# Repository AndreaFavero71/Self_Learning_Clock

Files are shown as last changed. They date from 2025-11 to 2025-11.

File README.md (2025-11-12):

# Self-learning clock (SLC)

a DIY clock that learns its own internal drift to maintain high accuracy with minimal NTP synchronizations

It uses an ultra-low power development board, paired with a 4.2-inch, high-contrast e-paper display.
The clock is battery-operated, and one charge should last for months; I'll provide precise battery life data in due time.
<br><br>
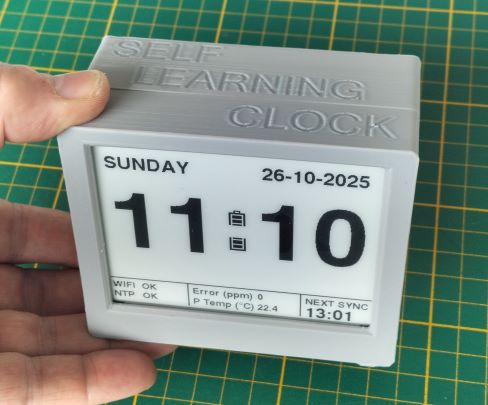
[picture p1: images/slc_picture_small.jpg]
title image
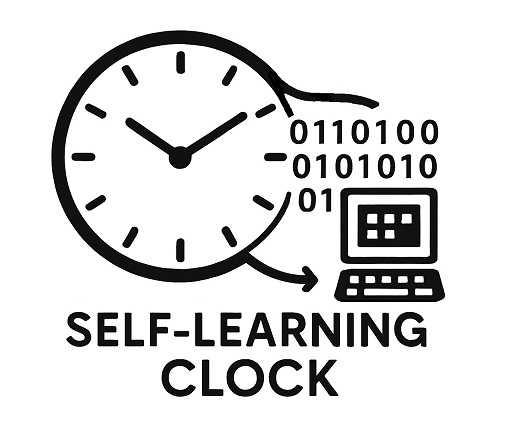
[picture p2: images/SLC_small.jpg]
title image


<br><br>
## Repo content
- all the Micropython files
- the Gerber files to make the Connections board

<br><br>
## For more information
More detailed informations at my [Instructables page](https://www.instructables.com/Self-Learning-Clock-SLC/)

<br><br>
## The Concept

Traditional NTP-based clocks frequently check in with time servers, which drains power and relies on a continuous network connection.
Their accuracy drifts until the next sync.

The Self-Learning Clock (SLC) takes a different approach: it observes its own timing errors and builds a software correction model for its internal oscillator's drift.

By applying this adaptive correction, it achieves excellent short-term accuracy and minimal long-term drift (the last gets fully compensated at NTP syncs).

After an initial learning period, the clock maintains an accuracy of approximately ±2 seconds over a 12-hour period, with just two NTP syncs per day.

The initial learning takes about two days, but the learning process never stops, allowing the SLC to continuously refine its corrections.

A high-level flowchart is attached, which better explains how the system works.

After researching online, I could not find any prior project with this specific approach. While there are many accurate timekeeping solutions available, I wanted to see how far I could push the accuracy of a microcontroller's own hardware, in a battery-operated device, and I'm quite pleased with the results.

<br><br>
## Why This Matters:
Microcontrollers like the ESP32 contain two types of oscillators:
- High-power mode: Uses a stable and precise crystal oscillator.
- Low-power mode (light sleep): Uses energy-efficient but imprecise RC oscillators that can accumulate minutes of error per day.

While external RTC modules with backup batteries can solve this problem, the SLC achieves similar precision using only the microcontroller itself.
This enables true, long-lasting battery operation without any additional hardware.

<br><br>
## Why "Self-Learning"?
In this context, "learning" refers to a deterministic self-calibration process.

The clock models and compensates for its own hardware characteristics. It's not artificial intelligence, but a straightforward mathematical analysis.

The system compares the internal clock deviation (in PPM) against a trusted source (NTP servers) and applies a filtered correction to the displayed time.

<br><br>
## Key features

#### Adaptive Drift Compensation:
- Learns and corrects the microcontroller's oscillator drift through periodic NTP synchronization, creating an increasingly accurate internal timing model.
- There is no need to manually calibrate the resonator; the code handles compensation automatically.
- Ultra-Low Power Consumption (<0.75 mAh average):
- Implements finely tuned light-sleep cycles with ultra-short wakeups (≈0.8 seconds active per minute).

#### Smart Time Management:
- Automatically handles time zones and Daylight Saving Time (DST) with configurable rules for different regions (e.g., EU, US, Australia).

#### High-Contrast 4.2" E-Paper Display:
- Features gigantic 110-point digits for excellent readability.
- It uses partial refreshes for efficiency and a full refresh every 60 updates to prevent ghosting.
- The display updates immediately after the minute changes (when seconds are between 0 and 5).
- #### The display also shows useful status information:
  - Battery level (displayed in place of the colon between hours and minutes)
  - Residual timing error (in PPM)
  - Microprocessor temperature (°C/°F)
  - Time of the next NTP sync
  - Status of the last WiFi connection
  - Status of the last NTP synchronization

#### WiFi Connectivity:
- The clock requires a WiFi network for NTP synchronization. While this is a limiting factor, WiFi is common in most modern homes.

#### Additional Notes:
The learning and correction process continuously adapts to variations that might arise from temperature changes or component aging.

The very small duty cycle (<1.5%) drastically limits the microprocessor's self-heating, allowing it to be 'sealed' in an enclosure.
This isolation protects the processor from sudden room temperature fluctuations, leading to a more stable drift characteristic.

Long-term accuracy validation is an ongoing process: The more precise the clock becomes, the longer the test period required to characterize its performance fully.

So far, the longest continuous test run has been one week, and I will provide more detailed long-term data as it becomes available.

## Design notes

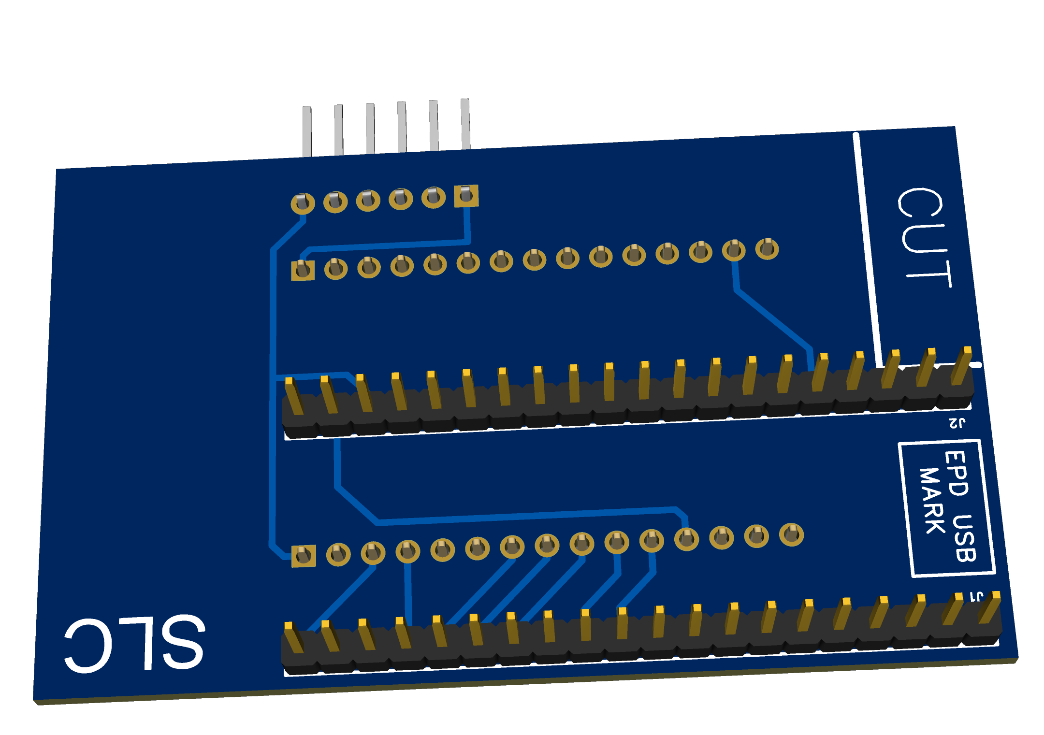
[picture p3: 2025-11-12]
board/3D_PCB1_2025-10-22 (7).png

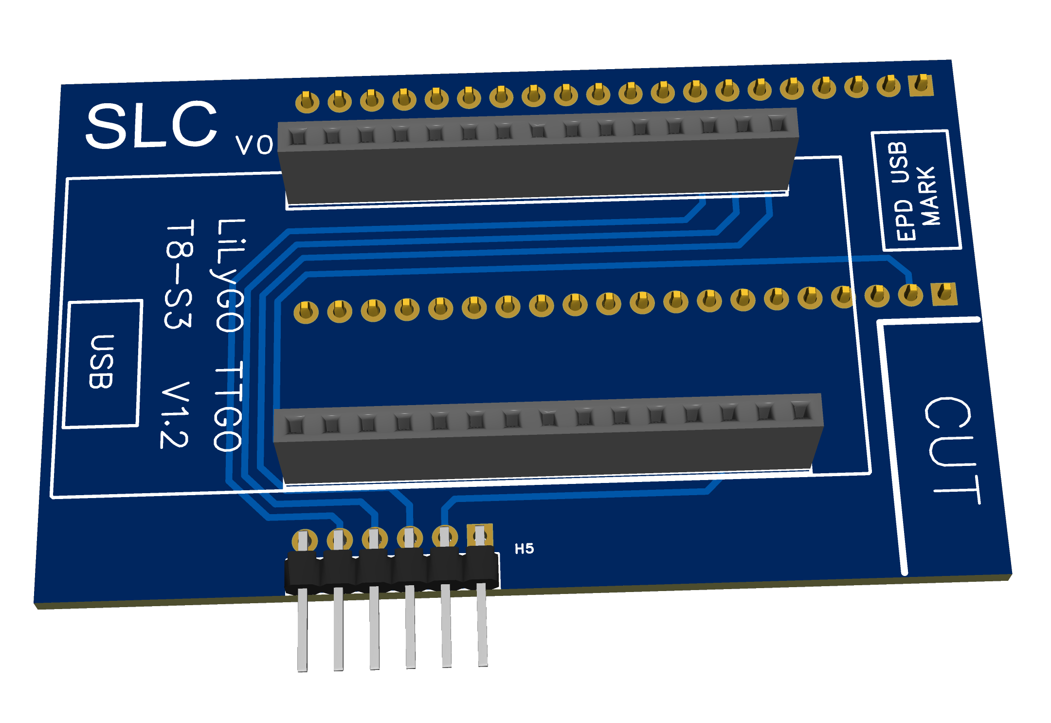
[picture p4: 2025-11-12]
board/3D_PCB1_2025-10-22.png

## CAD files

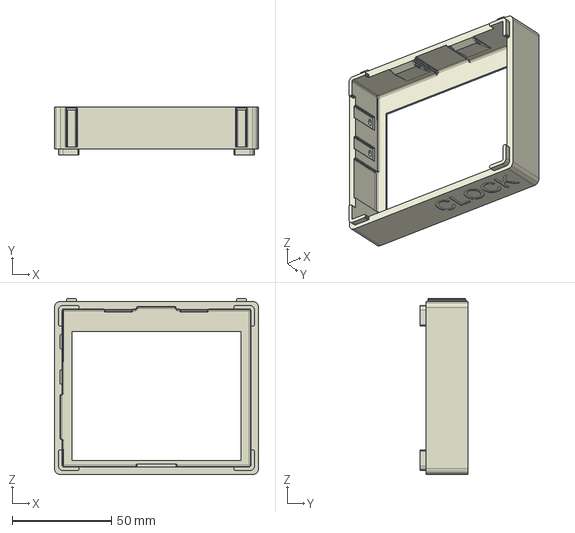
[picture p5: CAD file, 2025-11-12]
3d_model/step/front_v4.stp
102.6 x 24.1 x 88.6 mm

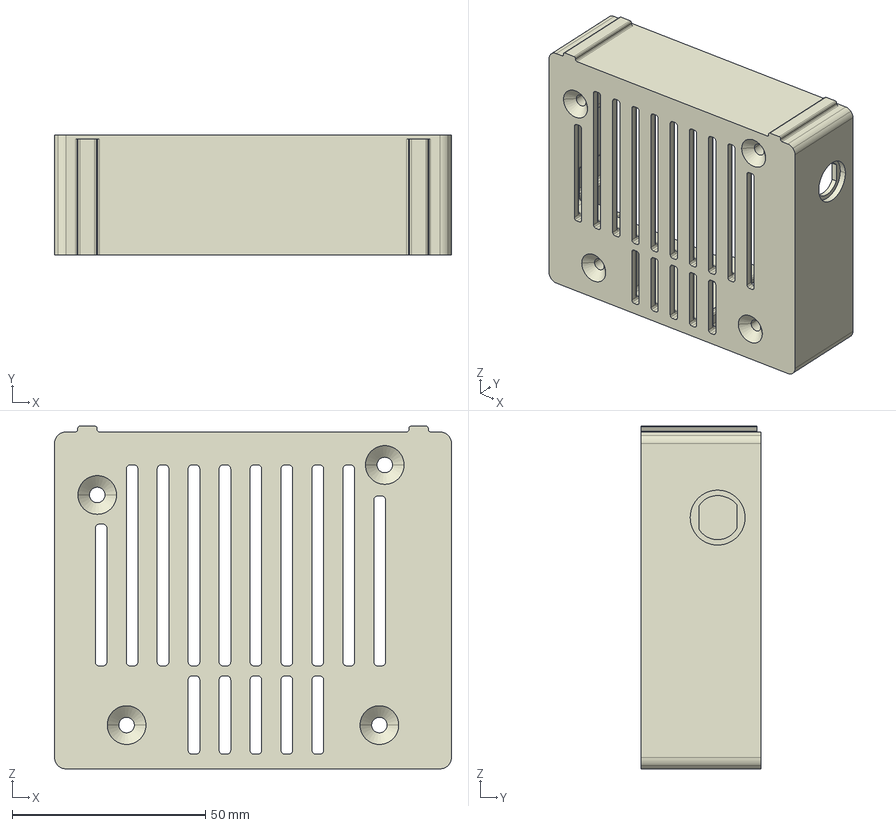
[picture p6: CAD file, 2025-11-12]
3d_model/step/back_v5_LP785060.stp
102.6 x 30.9 x 88.6 mm

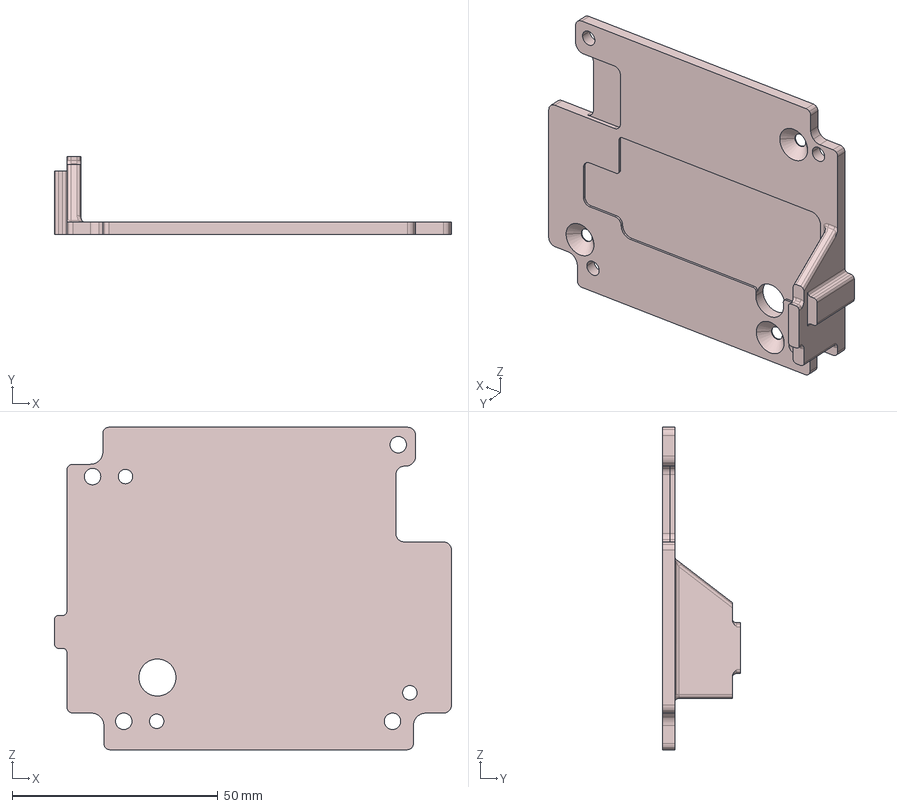
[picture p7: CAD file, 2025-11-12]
3d_model/step/panel_v4_LP773575.stp
96.5 x 19.0 x 78.4 mm

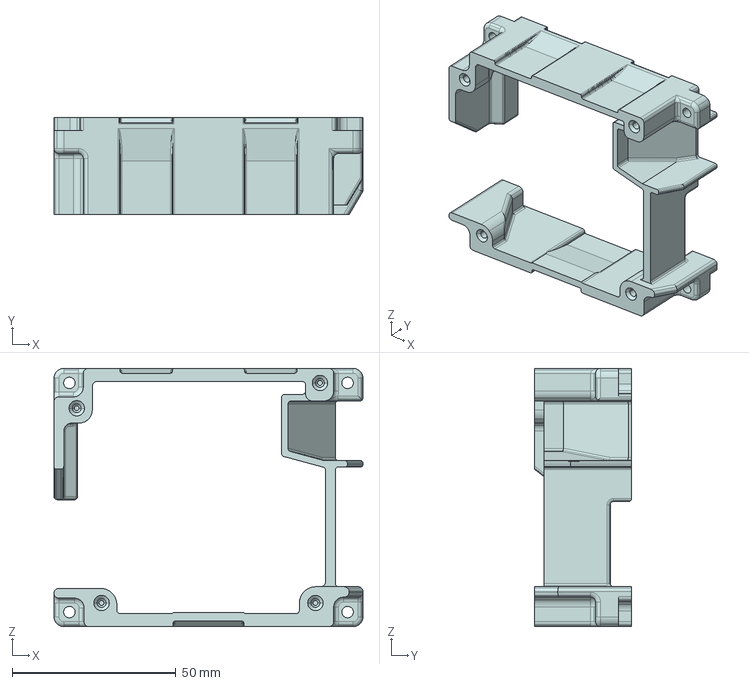
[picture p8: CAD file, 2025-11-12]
3d_model/step/frame_v4.stp
94.4 x 29.7 x 78.9 mm

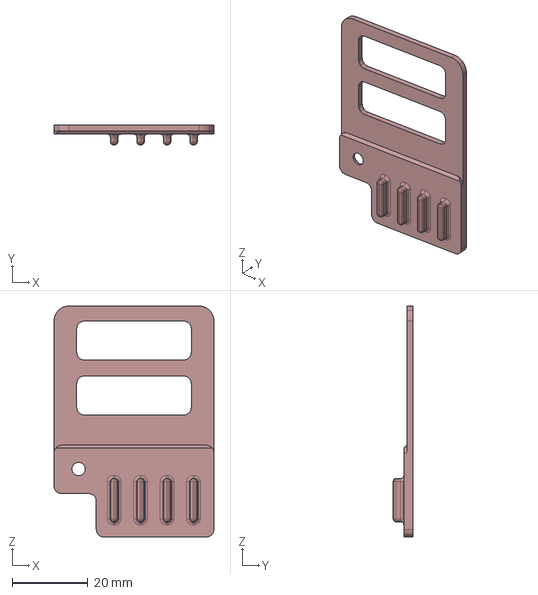
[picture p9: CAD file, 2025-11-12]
3d_model/step/clip_v5.stp
42.3 x 5.20 x 61.0 mm

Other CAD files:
3d_model/step/panel_v5_LP785060.stp

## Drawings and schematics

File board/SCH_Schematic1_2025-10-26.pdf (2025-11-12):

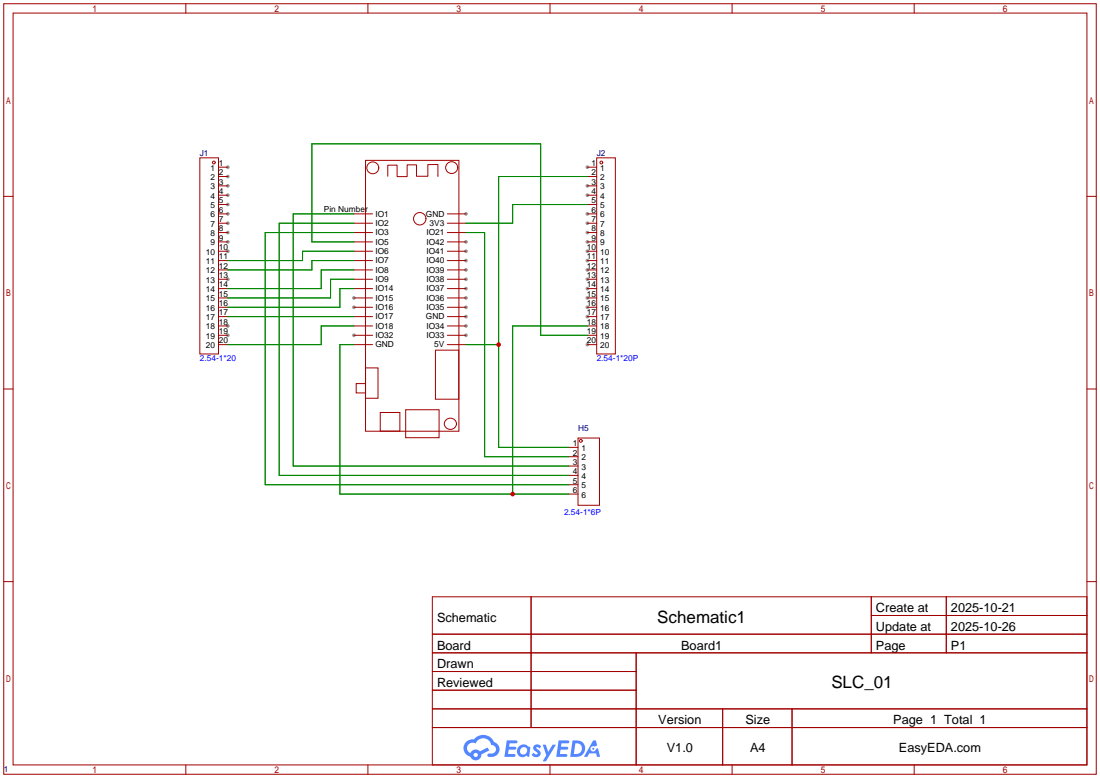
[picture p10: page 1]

Schematic | Schematic1 | Create at | 2025-10-21

Update at | 2025-10-26

Board | Board1 | Page | P1
Drawn | | SLC_01
Reviewed

Version | Size | Page 1 Total 1
V1.0 | A4 | EasyEDA.com

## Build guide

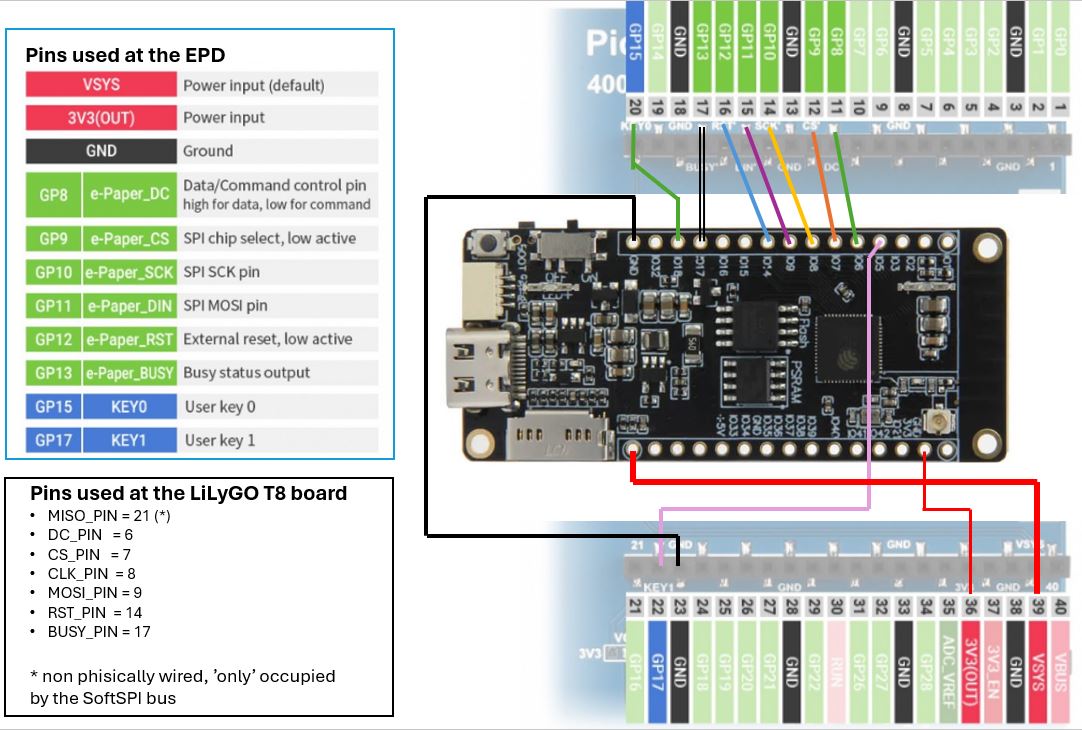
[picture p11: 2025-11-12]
board/Wiring.JPG

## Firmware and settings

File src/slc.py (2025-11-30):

"""
Andrea Favero 20251130


Self-Learning Clock (MicroPython)

More info at:
  https://github.com/AndreaFavero71/Self_Learning_Clock
  https://www.instructables.com/Self-Learning-Clock-SLC/


NTP is used to periodically discipline the clock.
The MCU’s internal clock interval (ticks counting) is compared with the one obtained via NTP,
allowing the system to learn its own drift and self-correct between synchronizations.
The internal timing mechanism itself is not altered by these corrections; instead, the
displayed time is adjusted to minimize deviation. This approach reduces time drift while
lowering the NTP synchronization frequency, thereby minimizing energy consumption.

The display refresh cadence is adapted so that the new time is updated when the
interpreted seconds fall between 0 and 5 of each minute.
Light-sleep duration is maximized to reduce power consumption in battery-operated clocks.
The code has been developed on a LilyGO T8 development board (ESP32-S3 based, with 8 MB PSRAM)

The used display is a Waveshare 4.2-inch (400×300) 4-grayscale e-paper Pico version:
https://www.waveshare.com/wiki/Pico-ePaper-4.2

(Optional) If predefined SSID/passwords are not available, or fail to connect, the code automatically
searches for open networks, check settings at config.py.




MIT License

Copyright (c) 2025 Andrea Favero

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

__version__ = "0.2.1"


# import standard modules
from utime import ticks_ms, gmtime, time, sleep_ms, ticks_diff
from esp32 import NVS, mcu_temperature
from machine import lightsleep
from collections import deque
import uasyncio as asyncio
import sys, gc

# import SLC custom modules
from network_manager import NetworkManager
from time_manager import TimeManager
from display_manager import Display
from battery_manager import Battery
from wdt_manager import WDTManager
from lib.config import config



class SelfLearningClock:
    def __init__(self, logo_time_ms):
        
        if config.DEBUG:
            print()
            print("#" * 41)
            print("#  Clock started. Press Ctrl+C to stop  #")
            print("#" * 41)
            print()
        
        
        # reducing ESP32-S3 frequency to lower power consumption
        # 80MHz is the minimum allowed frequency to maintain wlan function
        freq = 80_000_000
        
        # check presence or make a folder for the log related files
        self._make_folder("log")
        
        # initialize the module for time management
        self.time_mgr = TimeManager(config)
        
        # initialize WDT manager, before the modules where it is passed
        if config.WDT_ENABLED:
            self.wdt_manager = WDTManager()
        else:
            self.wdt_manager = False
        
        # initialize display module, by also passing the WDT manager
        self.display = Display(wdt_manager = self.wdt_manager,
                               lightsleep_active = config.LIGHTSLEEP_USAGE,
                               battery = config.BATTERY,
                               degrees = config.TEMP_DEGREES,
                               hour12 = config.HOUR_12_FORMAT,
                               am_pm_label = config.AM_PM_LABEL,
                               debug = config.DEBUG,
                               logo_time_ms = logo_time_ms
                               )
        
        # initialize the network manager module, by also passing the WDT manager
        self.network_mgr = NetworkManager(self.wdt_manager)

        # case of error on initializing the network manager
        if not self.network_mgr.secrets:
            # error info is showed to the display and code is stopped
            self.display.text_on_logo("ERROR: SECRETS.JSON", x=-1, y=-1, show_time_ms=2000)
            
            if config.DEBUG:
                print("[ERROR]    Issues with the secret.json file in /lib folder")
                print("[INFO]     If you aim using open networks, set OPEN_NETWORKS as True in config.py")
            
            # code is stopped
            sys.exit(1)
        
        # case of battery, initialize the battery manager module
        if config.BATTERY:
            self.battery = Battery(debug=config.DEBUG)
        else:                       # case of no battery
            self.batt_voltage = -1  # assign an arbitrary value to the variable 
            self.batt_level = -1    # assign an arbitrary value to the variable
        
        # initialize WDT (after all components are initialized)
        if config.WDT_ENABLED:
            self.wdt_manager.initialize() 
        
        # initialize global variables
        self.smoothed_drift_ppm = 0
        self.last_smoothed_drift_ppm = 0
        self.current_sync_interval_ms = config.NTP_SYNC_INTERVAL_MS
        self.display_interval_ms = max(60000, config.DISPLAY_REFRESH_MS)     # EPD refresh time must be at least 60 secs (nominal)
        self.max_display_interval_ms = int(1.1 * self.display_interval_ms)   # adapted min EPD refresh time is 0.9 x
        self.min_display_interval_ms = int(0.9 * self.display_interval_ms)   # adapted max EPD refresh time is 1.1 x

        # timekeeping variables
        self.last_ntp_sync_ticks_ms = 0
        self.last_ntp_epoch_ms = 0
        self.last_ntp_epoch_s = 0
        self.ntp_total_delay_ms = 0
        self.ntp_offset_ms = 0
        self.time_tuple = (0,0,0,0,0,0)
        self.last_sync_day = -1
        self.next_sync = '99:99'
        
        # state variables
        self.first_cycle = True
        self.epd_full_update = False
        self.upload_files = False
        self.cycle_counter = 0
        self.sync_count = 0
        self.display_update_count = 0 
        
        # temperature smoothing
        self.mcu_temp = deque([], 16)
        
        # lists for trend analysis
        if config.DEBUG or config.PUSH_FILE_ENABLED:
            datapoints = 50
            self.mcu_temp_list = deque([], datapoints)
            self.error_ms_list = deque([], datapoints)
            self.correction_ms_list = deque([], datapoints)
            self.measured_drift_ppm_list = deque([], datapoints)
            self.smoothed_drift_ppm_list = deque([], datapoints)
            self.ntp_offset_ms_list = deque([], datapoints)
            self.ntp_tot_delay_ms_list = deque([], datapoints)
            self.ntp_rnd_latency_ms_list = deque([], datapoints)
            self.display_interval_ms_list = deque([], datapoints)
        
        ##############################################################
        ##############################################################
        # force wdt operation for debug purpose (do not uncomment it)
        # for i in range(3):
        #    self.network_mgr.feed_wdt(label="test wdt")
        #    sleep_ms(int(1.3 * config.DISPLAY_REFRESH_MS))
        ##############################################################
        ##############################################################
        
        
    
    def get_reset_reason(self):
        """Checks the reason for the MCU boot"""
        from machine import reset_cause, PWRON_RESET, HARD_RESET, WDT_RESET, DEEPSLEEP_RESET, SOFT_RESET
        
        reset_reason, reset_message = None, None
        reset_reason = reset_cause()
        reset_message = {
            PWRON_RESET: "POWER-ON RESET",
            HARD_RESET: "HARD RESET",
            WDT_RESET: "WATCHDOG RESET",
            DEEPSLEEP_RESET: "DEEPSLEEP WAKE",
            SOFT_RESET: "SOFT RESET"
        }.get(reset_reason, f"???: {reset_reason}")
        
        del reset_cause, PWRON_RESET, HARD_RESET, WDT_RESET, DEEPSLEEP_RESET, SOFT_RESET
        return reset_reason, reset_message
    
    
    
    
    def write_reset_reason(self, reset_reason, reset_msg):
        """Writes the reset reason to a text file, trimming old entries if needed."""

        MAX_RECORDS = 100

        # feed watchdog
        self.network_mgr.feed_wdt(label="write_reset_reason")

        try:
            # try reading existing lines (if file exists)
            try:
                with open(config.RESET_FILE_NAME, "r") as f:
                    lines = f.readlines()
            except OSError:
                lines = []

            # build the new log line
            timestamp = gmtime(time())  # (year, month, mday, hour, minute, second, ...)
            formatted_time = f"{timestamp[0]:04d}-{timestamp[1]:02d}-{timestamp[2]:02d} {timestamp[3]:02d}:{timestamp[4]:02d}:{timestamp[5]:02d}"
            new_line = f"Time: {formatted_time},  RST_reason: {reset_reason},  RST_msg: {reset_msg}\n"

            # append and trim if necessary
            lines.append(new_line)
            if len(lines) > MAX_RECORDS:
                lines = lines[-MAX_RECORDS:]

            # rewrite the file
            with open(config.RESET_FILE_NAME, "w") as f:
                for line in lines:
                    f.write(str(line))

        except Exception as e:
            if config.DEBUG:
                print(f"[ERROR]    Failed to write reset reason: {e}")
    
    
    
    
    def get_discipline(self, key=1):
        """Read discipline factor from NVS"""
        
        if config.QUICK_CHECK and config.DEBUG:
            print("\n[DEBUG]    Existing 'discipline factor' is not loaded when config.QUICK_CHECK")
            return None
        
        try:
            nvs = NVS("storage")
            buffer = bytearray(16)
            nvs.get_blob(str(key), buffer)
            value = buffer.decode().strip('\x00') 
            if config.DEBUG:
                print(f"[DEBUG]    A discipline factor was available: {value}")
            return self._convert_to_number(value)
        
        except Exception as e:
            if config.DEBUG:
                if e.errno == -0x1102:
                    print("[DEBUG]    Variable 'discipline factor' not found (not saved in esp32.NSV yet)")
                else:
                    print(f"[ERROR]    Issue on reading from esp32.NSV: {e}")
            return None
    
    
    
    def save_discipline(self, discipline_factor, key=1):
        """Save discipline factor to NVS"""
        
        if config.QUICK_CHECK and config.DEBUG:
            print("[DEBUG]    Variable 'discipline factor' is not saved when config.QUICK_CHECK")
            return None
        
        try:
            nvs = NVS("storage")
            nvs.set_blob(str(key), str(discipline_factor).encode())
            nvs.commit()
        except Exception as e:
            if config.DEBUG:
                print(f"[ERROR]   Issue on saving to esp32.NSV: {e}")
            raise
    
    
    
    def write_to_csv(self, epoch, temp, error_ms, ntp_offset_ms, rnd_latency_ms, tot_latency_ms):
        """
        Writes the stats on a tab separated file, trimming the file if too large.
        File trimming is made in RAM, and it considers a small file size.
        """

        MAX_RECORDS = 200  # keep only the newest 200 records (excluding header)

        if config.DEBUG:
            print(f"[DEBUG]    write_to_csv called with epoch={epoch}, file={self.stats_file_name}")

        self.network_mgr.feed_wdt(label="write_to_csv")

        try:
            # create file with header if not yet done
            if not hasattr(self, "csv_header_written"):
                with open(self.stats_file_name, "w") as file:
                    header = ("epoch\ttemp\terror_ms\tcorrection_ms\tdrift_ppm\t"
                              "ntp_offset_ms\trnd_latency_ms\ttot_latency_ms\t"
                              "smoothed_ppm\tdisplay_interval_ms\tbatt_voltage\t"
                              "battery_level\n")
                    file.write(header)
                self.csv_header_written = True

            # read existing lines
            try:
                with open(self.stats_file_name, "r") as file:
                    lines = file.readlines()
            except OSError:
                # file may not exist yet
                lines = ["epoch\ttemp\terror_ms\tcorrection_ms\tdrift_ppm\t"
                         "ntp_offset_ms\trnd_latency_ms\ttot_latency_ms\t"
                         "smoothed_ppm\tdisplay_interval_ms\tbatt_voltage\t"
                         "battery_level\n"]

            # build new data line
            new_line = (
                f"{epoch}\t{temp:.2f}\t{error_ms}\t{self.correction_ms}\t"
                f"{self.measured_drift_ppm:.6f}\t{ntp_offset_ms}\t{rnd_latency_ms}\t"
                f"{tot_latency_ms}\t{self.smoothed_drift_ppm:.6f}\t{self.display_interval_ms}\t"
                f"{self.batt_voltage}\t{round(self.batt_level,3)}\n"
            )

            # append and trim if necessary
            lines.append(new_line)

            # first line is header → data start from index 1
            if len(lines) - 1 > MAX_RECORDS:
                # keep header + last MAX_RECORDS lines
                lines = [lines[0]] + lines[-MAX_RECORDS:]

            # write back
            with open(self.stats_file_name, "w") as file:
                for line in lines:
                    file.write(line)

        except Exception as e:
            print(f"[ERROR]    write_to_csv failed: {e}")
            raise
    

    
    
    def get_temperature(self):
        """Get temperature from MCU"""

        # wdt feeding
        self.network_mgr.feed_wdt(label="get_temperature")
        
        # temp threshold (celsius) to plot a warning on the display
        t_warning_c = 50
        
        # gets the MCU temperature
        temperature_c = mcu_temperature()
        
        # case Celsius is set at the config.py
        if config.TEMP_DEGREES == "C":
            temperature = temperature_c
            if temperature_c > t_warning_c:
                self.display.text_on_logo(f"PROCESSOR TEMP {round(temperature_c,0)} C", x=-1, y=-1, show_time_ms=20000)
        
        # case Fahrenheit is set at the config.py
        elif config.TEMP_DEGREES == "F":
            temperature = self._c_to_f(temperature_c)
            if temperature_c > t_warning_c:
                self.display.text_on_logo(f"PROCESSOR TEMP {round(temperature,0)} F", x=-1, y=-1, show_time_ms=20000)
        else:
            if config.DEBUG:
                print("[ERROR]   TEMP_DEGREES at config must be 'C' or 'F' ")
            self.display.text_on_logo("ERROR: C or F DEG.", x=-1, y=-1, show_time_ms=20000)
            
            # forced garbage collection
            gc.collect()
        
        # averaging the temperatures previouly gathered
        if len(self.mcu_temp) > 0:
            avg_temp = sum(self.mcu_temp)/len(self.mcu_temp)
        else:
            avg_temp = temperature
        
        # append the last temp measured
        self.mcu_temp.append(temperature)
        
        # low-pass filter
        temp = 0.8 * avg_temp + 0.2 * temperature

        return round(temp, 2)
    
    
    
    
    def update_display(self, current_temp, plot_all=False):
        """
        Update the display
        When plot_all is False then only the changed fields gets updated on the display.
        When plot_all is True, all the fields and graphics gets updated on the display.
        Tipically, the plot_all=False is managed as partial_update technology of the EPD,
        unless it is time for a full refress (preventing ghosting).
        """
        
        # wdt feeding
        self.network_mgr.feed_wdt(label="update_display_1")
        
        try:    
            
            # retrieve the single gigits for hour and minute
            H1, H2, M1, M2, am = self.time_mgr.get_time_digits(self.time_tuple)
            
            # retrieve the date fields
            dd, day, d_string = self.time_mgr.get_date(self.time_tuple)
            
            # forced garbage collection
            gc.collect()
            
            # set the battery_low flag as False
            battery_low = False
            
            # if battery presence and its voltage below threshold
            if config.BATTERY and self.batt_voltage < config.BATTERY_WARNING:
                # set the battery_low flag as True
                battery_low = True
            
            # send the updated info to the display Class
            self.display.show_data(H1, H2, M1, M2, dd, day, d_string, current_temp, self.batt_level,
                                   self.res_error_ppm, self.next_sync, self.network_mgr.wifi_bool,
                                   self.network_mgr.ntp_bool, am, battery_low=battery_low, plot_all=plot_all)

            # wdt feeding
            self.network_mgr.feed_wdt(label="update_display_2")
        
        except Exception as e:
            if config.DEBUG:
                print(f"[ERROR]    Display error: {e}")
            raise
    
    
    
    
    def goto_sleep(self, total_sleep_ms):
        """Function handling the needed steps to enter lightsleep"""
        
        # wdt feeding
        self.network_mgr.feed_wdt(label="goto_sleep_1")
                    
        # sleeping time must be positive
        total_sleep_ms = max(0, total_sleep_ms)
        
        # case the lightsleep is set False
        if not config.LIGHTSLEEP_USAGE:
            if config.DEBUG:
                print(f"[DEBUG]    Going to sleep for {total_sleep_ms} ms")
            
            # normal sleeping function is used instead of the lighsleep one
            sleep_ms(total_sleep_ms)
        
        # case the lightsleep is set True
        elif config.LIGHTSLEEP_USAGE:
            
            # case the radio is still active
            if self.network_mgr.wlan.active() or self.network_mgr.wlan.isconnected():
                
                # disable the radio, and track the needed ime
                wlan_disabling_t_ms = self.network_mgr.disable_wifi()
                
                if total_sleep_ms > wlan_disabling_t_ms:
                    total_sleep_ms -= wlan_disabling_t_ms
                else:
                    total_sleep_ms = 0
            
            # wdt feeding
            self.network_mgr.feed_wdt(label="goto_sleep_2")
            
            if config.DEBUG:
                t_enter_lightsleep_ms = ticks_ms()
                print(f"[DEBUG]    Entering lightsleep for {total_sleep_ms} ms")
            
            # entering the lightsleep period
            lightsleep(total_sleep_ms)
            
            if config.DEBUG:
                print("[DEBUG]    Quitting lightsleep")
        
        # wdt feeding
        self.network_mgr.feed_wdt(label="goto_sleep_3")
        
    
    
    
    
    async def run(self):
        """Main clock execution"""

        # NTP sync configuration based on clock time (not on elapsed period)
        # if Country uses DST, it is better to atrget 3:15, to get the time updated right after the official switch hour
        # if Country does not use DST, choose the time you prefer NTP sync (by night should be faster, draining less battery)
        # This control is only active after the initial learning (sync_interval_ms >= 8 hours)
        sync_target_hour = 3       # 3 (not 03) for 3 AM
        sync_target_minute = 15    # 15 (not :15) for 03:15 AM
        self.last_sync_day = -1    # last day NTP synced at target hour (-1 forces first time)
        
        # load discipline factor
        discipline_factor = self.get_discipline()
        
        # check the discipline_factor
        if discipline_factor is None:
            self.smoothed_drift_ppm = 0
            if config.DEBUG:
                print("[DEBUG]    Not available a prior discipline_factor, it will be saved in a few days from now")
        else:
            self.smoothed_drift_ppm = discipline_factor
            if config.DEBUG:
                print(f"[DEBUG]    Loaded the latest discipline_factor: {discipline_factor}")
        
        # assign smoothed_drift_ppm to last_smoothed_drift_ppm
        self.last_smoothed_drift_ppm = self.smoothed_drift_ppm
        
        # retieve the reset reason
        reset_reason, reset_msg = self.get_reset_reason()
        if config.DEBUG:
            print(f"\n[INFO]     Last reset reason: {reset_msg}\n")
        
        # save the reset reason to a text file
        self.write_reset_reason(reset_reason, reset_msg)

        # plot the SLC logo with the SLC code version
        self.display.text_on_logo(f"SLC  VERSION:  {__version__}", x=-1, y=-1, show_time_ms=5000)
        
        # plot the SLC logo with a custom text underneath
        self.display.text_on_logo("WIFI  CONNECTION  ...", x=-1, y=-1, show_time_ms=2000)
        
        # forced garbage collection
        gc.collect()
        
        # wdt feeding
        self.network_mgr.feed_wdt(label="before making 1st wlan")
        
        # initialize WiFi
        self.network_mgr.connect_to_wifi(blocking=True)
        
        # check if error due to wifi connection
        if not self.network_mgr.wifi_bool:
            self.display.text_on_logo("ERROR: WIFI NETWORKS", x=-1, y=-1, show_time_ms=2000)
            sys.exit(1)
        
        # check if the wifi has internet connection
        ret = await self.network_mgr.is_internet_available(blocking=True)
        
        # check if error due to internet access
        if not ret:
            self.display.text_on_logo("ERROR: NO INTERNET", x=-1, y=-1, show_time_ms=2000)
            sys.exit(1)
        
        # wdt feeding   
        self.network_mgr.feed_wdt(label="after making 1st wlan")
        
        # check the IP addresses of the NTP server(s)
        ntp_servers_ip = await self.network_mgr.get_ntp_servers_ip(repeats=5)
        
        # check if error ar resolving the NTP servers addresses (blocking)
        if len(ntp_servers_ip) == 0:
            self.display.text_on_logo("ERROR: NTP DNS", x=-1, y=-1, show_time_ms=0)
            sys.exit(1)
        
        # preparig for the real first NTP sync
        if config.DEBUG:
            print("\n[INFO]     Performing first NTP sync ...")
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

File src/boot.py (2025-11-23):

# This file is executed on every boot (including wake-boot from deepsleep)


##################################################################
# To get the code starting at the boot, uncomment the below code #
# Before doing so, ensures the code is running without errors    #
##################################################################



# from utime import sleep_ms
# t_ms = 20000
# print(f"\n\n{t_ms//2000} seconds sleep time to delay the WDT")
# print("This time should suffice to interrupt the code via CTRL + C (preventing automatic script execution)\n")
# sleep_ms(t_ms//2)
# 
# import asyncio
# import slc
# asyncio.run(slc.main(logo_time_ms=int(t_ms//2)))

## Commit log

2025-11-12 initial commit
    initial commit
    initial commit
    Added step files
    rev_01
    rev_01
    [back_v5_LP785060.stp, clip_v5.stp, frame_v4.stp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]
2025-11-23 rev 0.2.0
    Improved battery manager with clearer function separation and enhanced debug output. Refactored network manager for better handling of open networks, WiFi connection logic, and transmission power opt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
2025-11-30 Add 12-hour time format
    Introduces configuration options for 12-hour time format and AM/PM label in config.py. Updates display_manager, time_manager, and slc.py to support and render 12-hour time format and AM/PM indicators. Refactors file logging and trimming logic in network_manager, wdt_manager, and slc.py for better reliability and file size management. Minor bug fixes and code cleanups included.
    [slc.py]
